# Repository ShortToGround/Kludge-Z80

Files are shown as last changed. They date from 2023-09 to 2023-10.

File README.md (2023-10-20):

# Overview
This is my Z80 homebrew project. I am a total beginner and I'm learning as I go, but the goal is to create a functional kernel and OS based on a Z80 CPU.
The first goal is to get it working for my specific hardware set, the next goal will is to dynamically scan and load drivers as needed, depending on what "cards" are present on boot.

When I say "functional kernel" I mean a real (as real as you can get with a Z80) kernel. Complete with syscalls and memory management.

Programming wisdom says to write your code first and optimize later. I have no doubts that there are many places my code can be optimized.
I don't have a full grasp of every instruction so I will try to get it running first, then go back and make it faster/better later.

**Special thanks to the user Erlend_LB6MI at #electronics on libera IRC and the man behind the Zeal 8-Bit computer project for their guidance.
Check out the Zeal 8-bit computer [here](https://zeal8bit.com). His project is seriously impressive and he even created his own VFS from scratch. His kernel is complete with syscalls and everything. This project is what re-inspired me to finish mine!**

## Current hardware list
I recently switched from LS to HCT ICs for full CMOS Z80 and CF compatiblity.

### CPU/System:
* 1x Z80 CPU - Z84C0010PEG (CMOS)
* 1x Z80/System Clock - ECS-2100AX-100 (10MHz)
* 1x SRAM - CY62256NLL-70PXC (32K)
* 1x EEPROM - AT28C64B-15PU (Unused atm, I'm running everything off of RAM using my rom-uploader program)
* 1x Hex Inverter - SN74AHCT04N
* 1x NAND Gate (Used for some address "decoding")
* 1x OR Gate (Used to combine IOREQ RD/WR into IORD and IOWR. Same for MEMREQ)
* 1x 3-8 Address Decoder - SN74HCT138N
* A crap load of small and medium sized wire
* and a crap load of 104 ceramic capacitors for decoupling (before /u/1Davide on /r/ask_electronics says anything)
UART:
* 1x UART - PC16550DN/NOPB (I have a second one I will probably use for a tape interface one day)
* 1x UART Clock - ECS-100AX-018

### Programming "board"
* 1x Arduino Nano
* 2x Shift Register (Serial In, Parallel Out) - 7SN74HC595N (Wish these were HCT but it seems to work fine)

### Compact Flash:
* CF IDE breakout module

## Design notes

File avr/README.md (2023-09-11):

I think I will end up using some avr MCU's to create the PS/2 controller and maybe even the video circuit

So their source code will be included here when the time comes.

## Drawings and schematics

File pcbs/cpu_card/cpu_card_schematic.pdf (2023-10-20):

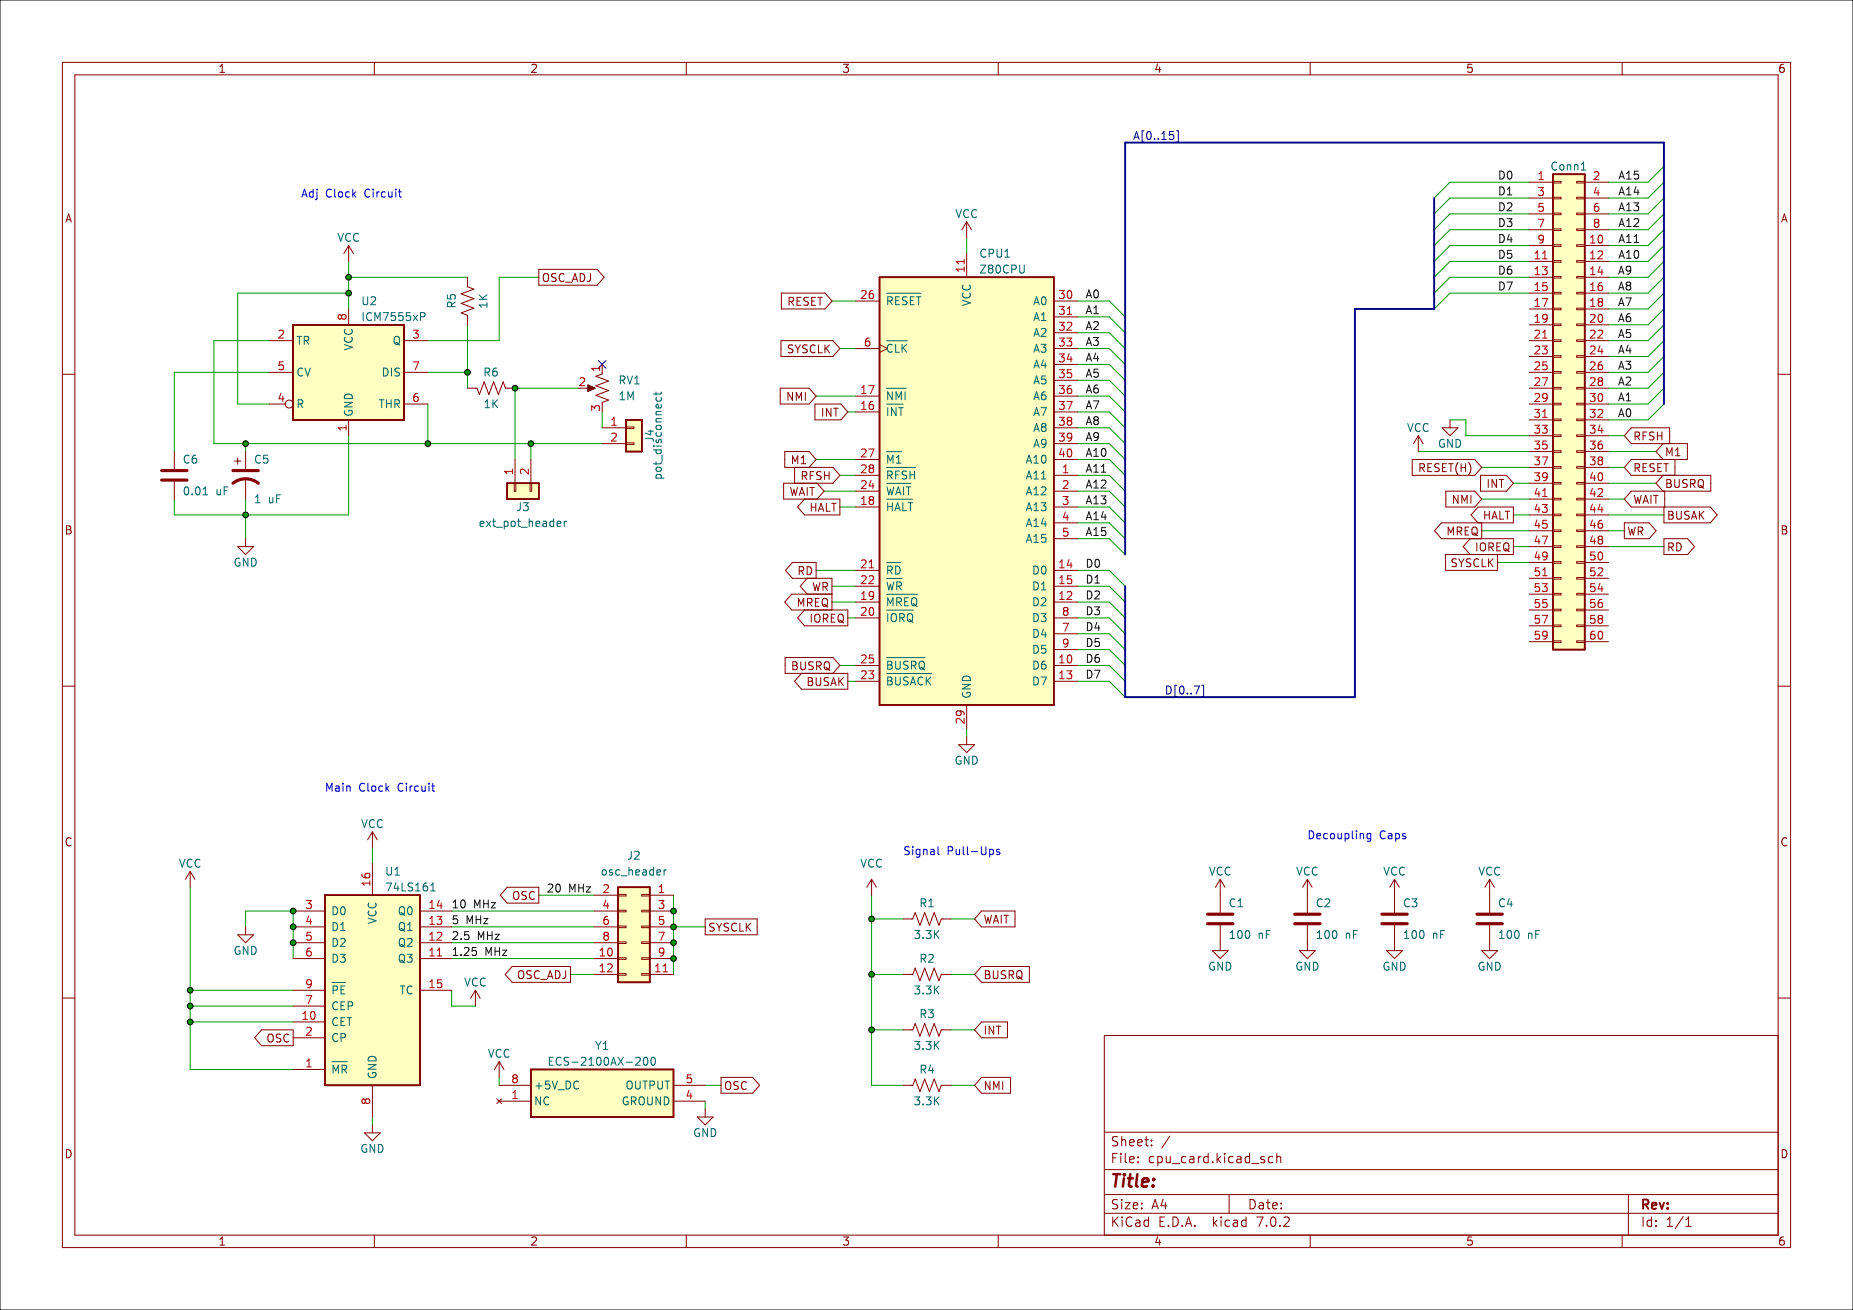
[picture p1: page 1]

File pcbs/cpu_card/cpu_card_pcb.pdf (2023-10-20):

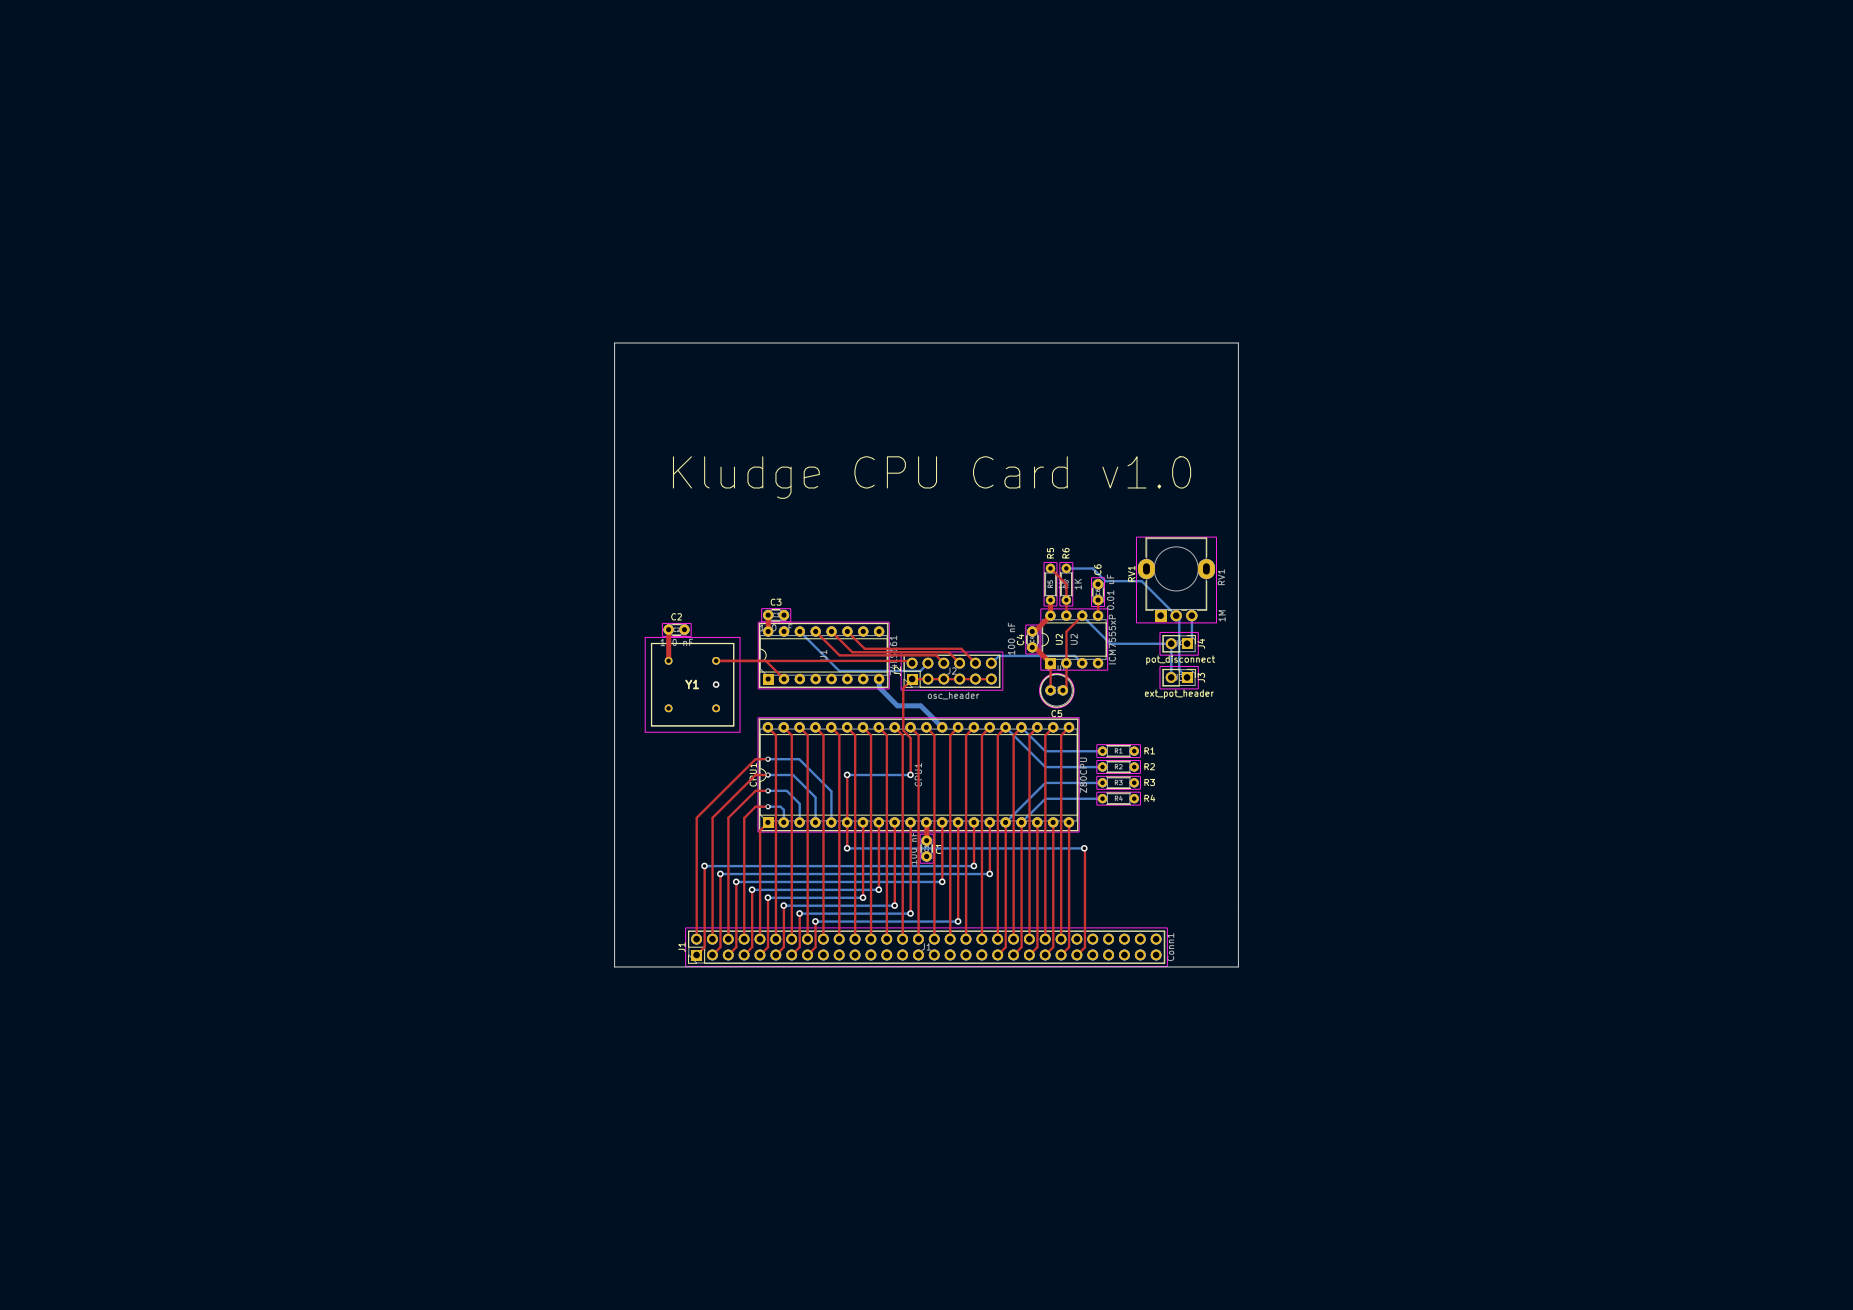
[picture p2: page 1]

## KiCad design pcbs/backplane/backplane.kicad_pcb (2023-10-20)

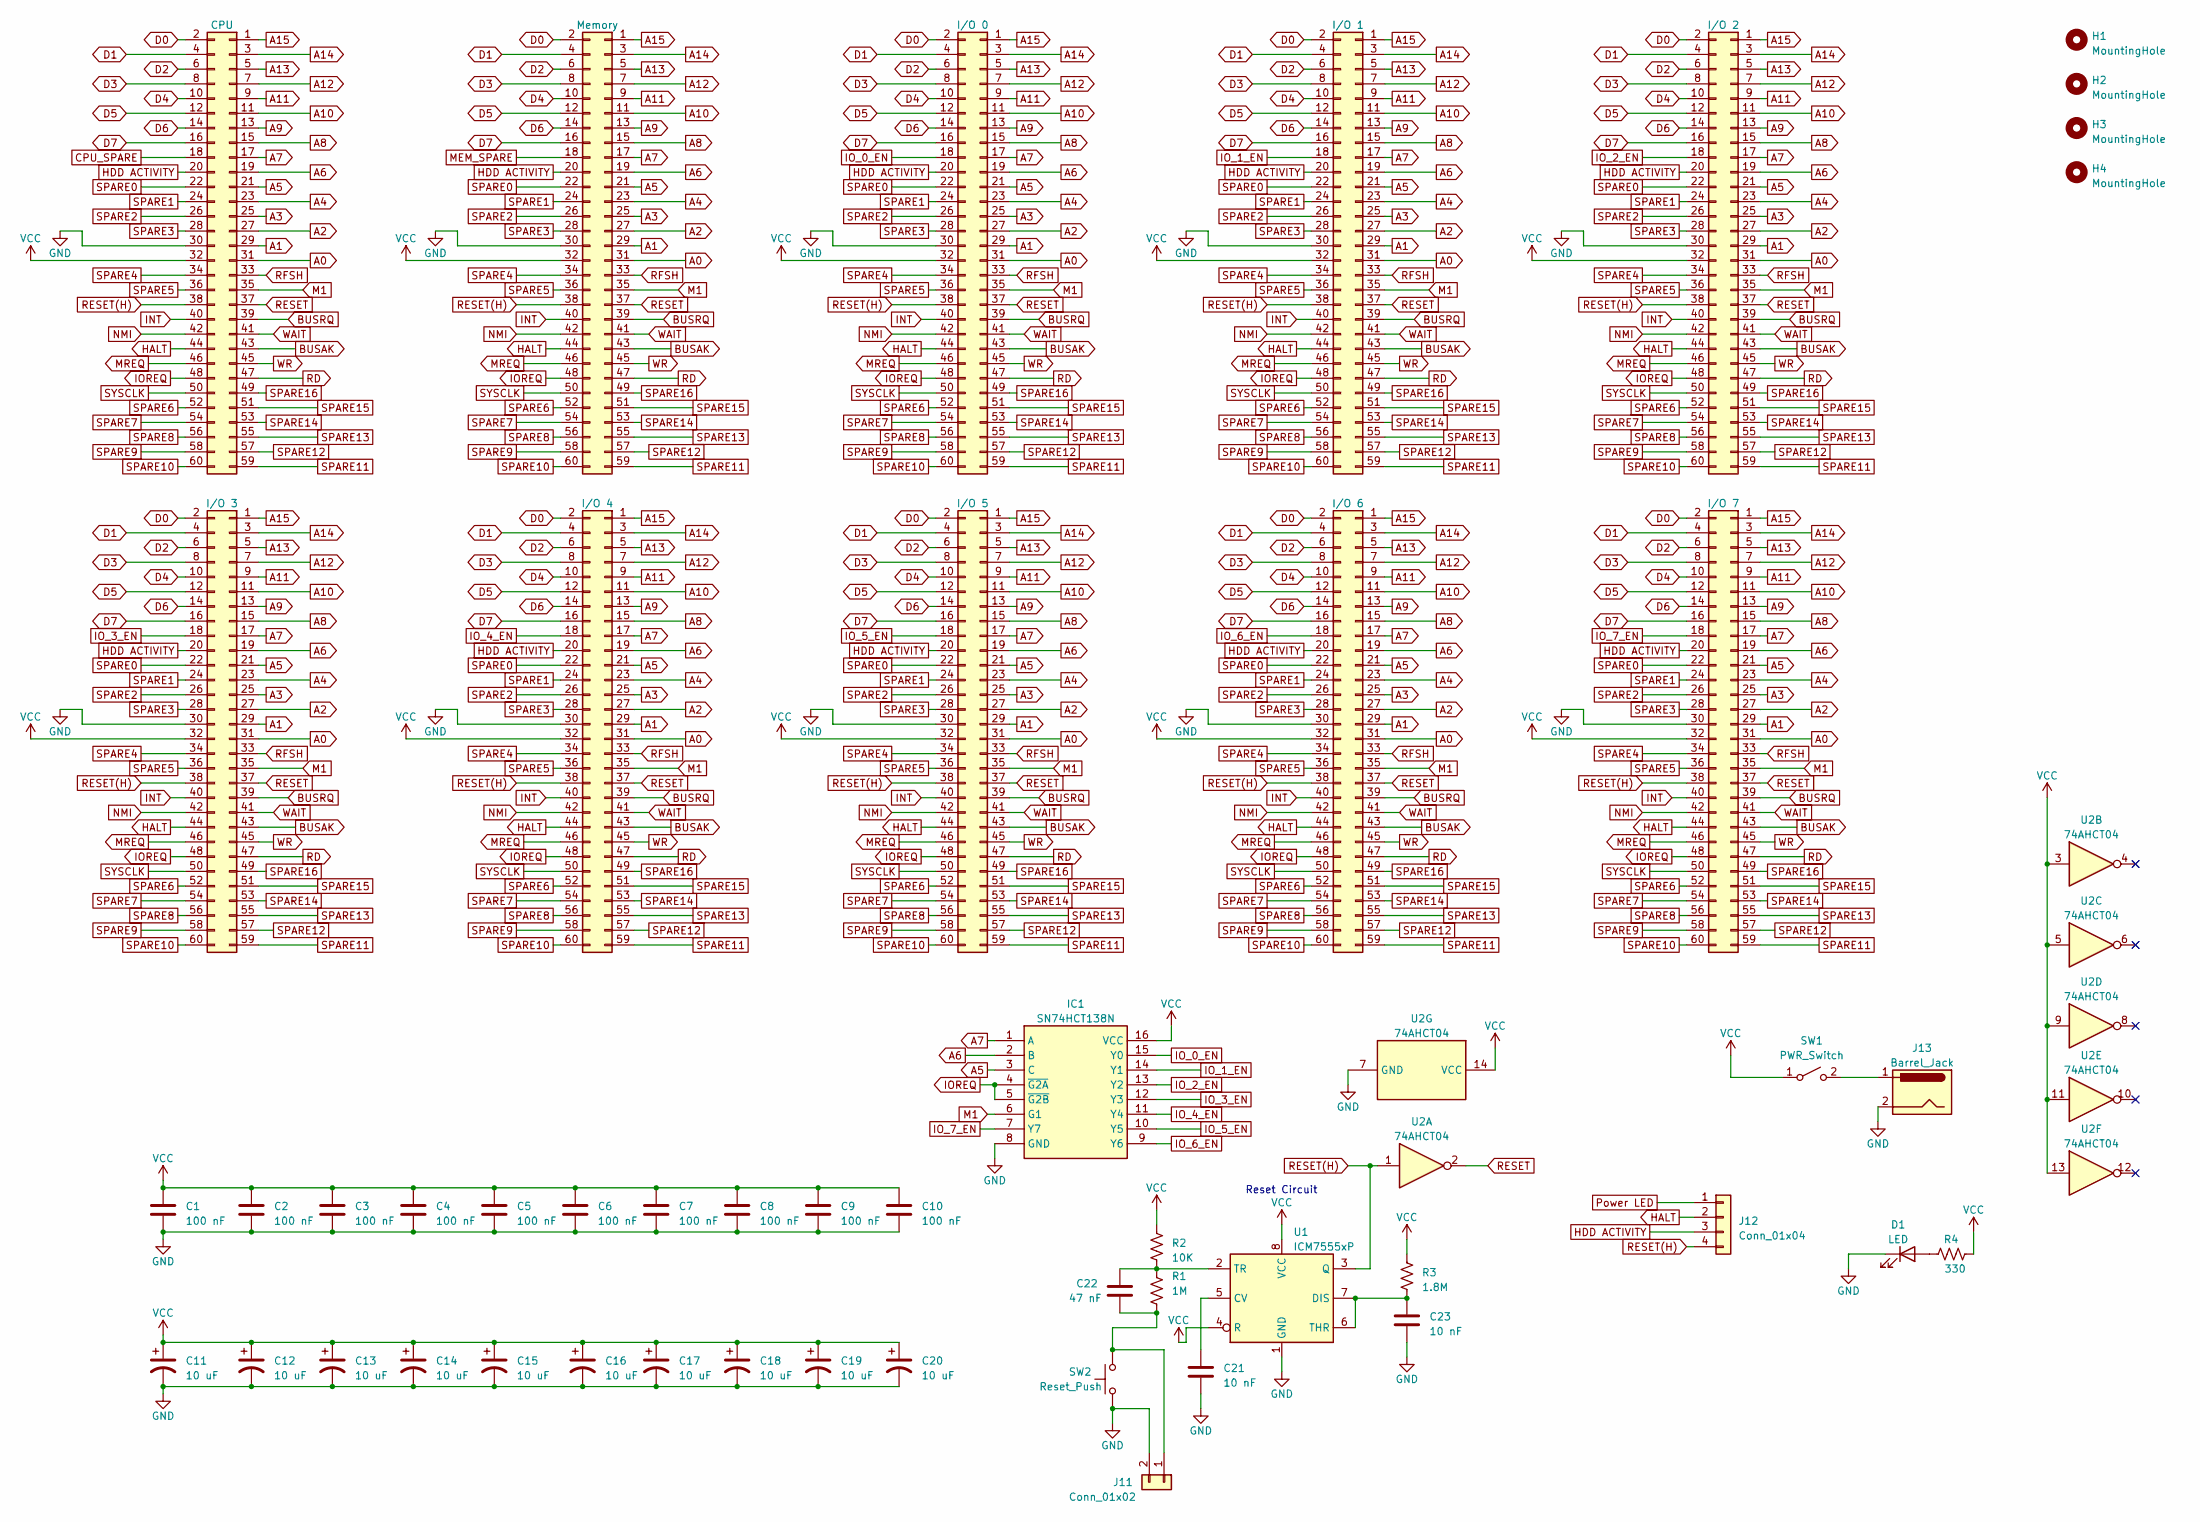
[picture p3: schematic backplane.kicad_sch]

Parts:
C1, C2, C3, C4, C5, C6, C7, C8, C9, C10: 100 nF; C_Disc_D3.0mm_W1.6mm_P2.50mm
C11, C12, C13, C14, C15, C16, C17, C18, C19, C20: 10 uF; C_Radial_D6.3mm_H7.0mm_P2.50mm
C21, C23: 10 nF; C_Disc_D3.0mm_W1.6mm_P2.50mm
C22: 47 nF; C_Disc_D3.0mm_W1.6mm_P2.50mm
D1: LED; LED_D3.0mm
H1, H2, H3, H4: MountingHole; MountingHole_3.2mm_M3
IC1: SN74HCT138N; Mouser Part Number 595-SN74HCT138N
J1: CPU; PinSocket_2x30_P2.54mm_Vertical
J2: Memory; PinSocket_2x30_P2.54mm_Vertical
J3: I/O 0; PinSocket_2x30_P2.54mm_Vertical
J4: I/O 1; PinSocket_2x30_P2.54mm_Vertical
J5: I/O 2; PinSocket_2x30_P2.54mm_Vertical
J6: I/O 3; PinSocket_2x30_P2.54mm_Vertical
J7: I/O 4; PinSocket_2x30_P2.54mm_Vertical
J8: I/O 5; PinSocket_2x30_P2.54mm_Vertical
J9: I/O 6; PinSocket_2x30_P2.54mm_Vertical
J10: I/O 7; PinSocket_2x30_P2.54mm_Vertical
J11: Conn_01x02; PinHeader_1x02_P2.54mm_Vertical
J12: Conn_01x04; PinHeader_1x04_P2.54mm_Vertical
J13: Barrel_Jack; BarrelJack_Horizontal
R1: 1M; R_Axial_DIN0204_L3.6mm_D1.6mm_P5.08mm_Horizontal
R2: 10K; R_Axial_DIN0204_L3.6mm_D1.6mm_P5.08mm_Horizontal
R3: 1.8M; R_Axial_DIN0204_L3.6mm_D1.6mm_P5.08mm_Horizontal
R4: 330; R_Axial_DIN0204_L3.6mm_D1.6mm_P5.08mm_Horizontal
SW1: PWR_Switch; SW_DIP_SPSTx01_Slide_9.78x4.72mm_W7.62mm_P2.54mm
SW2: Reset_Push; SW_PUSH_6mm
U1: ICM7555xP; DIP-8_W7.62mm
U2: 74AHCT04; DIP-14_W7.62mm

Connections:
A0: J1.31, J2.31, J3.31, J4.31, J5.31, J6.31, J7.31, J8.31, J9.31, J10.31
A1: J1.29, J2.29, J3.29, J4.29, J5.29, J6.29, J7.29, J8.29, J9.29, J10.29
A2: J1.27, J2.27, J3.27, J4.27, J5.27, J6.27, J7.27, J8.27, J9.27, J10.27
A3: J1.25, J2.25, J3.25, J4.25, J5.25, J6.25, J7.25, J8.25, J9.25, J10.25
A4: J1.23, J2.23, J3.23, J4.23, J5.23, J6.23, J7.23, J8.23, J9.23, J10.23
A5: IC1.3 (C), J1.21, J2.21, J3.21, J4.21, J5.21, J6.21, J7.21, J8.21, J9.21, J10.21
A6: IC1.2 (B), J1.19, J2.19, J3.19, J4.19, J5.19, J6.19, J7.19, J8.19, J9.19, J10.19
A7: IC1.1 (A), J1.17, J2.17, J3.17, J4.17, J5.17, J6.17, J7.17, J8.17, J9.17, J10.17
A8: J1.15, J2.15, J3.15, J4.15, J5.15, J6.15, J7.15, J8.15, J9.15, J10.15
A9: J1.13, J2.13, J3.13, J4.13, J5.13, J6.13, J7.13, J8.13, J9.13, J10.13
A10: J1.11, J2.11, J3.11, J4.11, J5.11, J6.11, J7.11, J8.11, J9.11, J10.11
A11: J1.9, J2.9, J3.9, J4.9, J5.9, J6.9, J7.9, J8.9, J9.9, J10.9
A12: J1.7, J2.7, J3.7, J4.7, J5.7, J6.7, J7.7, J8.7, J9.7, J10.7
A13: J1.5, J2.5, J3.5, J4.5, J5.5, J6.5, J7.5, J8.5, J9.5, J10.5
A14: J1.3, J2.3, J3.3, J4.3, J5.3, J6.3, J7.3, J8.3, J9.3, J10.3
A15: J1.1, J2.1, J3.1, J4.1, J5.1, J6.1, J7.1, J8.1, J9.1, J10.1
BUSAK: J1.43, J2.43, J3.43, J4.43, J5.43, J6.43, J7.43, J8.43, J9.43, J10.43
BUSRQ: J1.39, J2.39, J3.39, J4.39, J5.39, J6.39, J7.39, J8.39, J9.39, J10.39
CPU_SPARE: J1.18
D0: J1.2, J2.2, J3.2, J4.2, J5.2, J6.2, J7.2, J8.2, J9.2, J10.2
D1: J1.4, J2.4, J3.4, J4.4, J5.4, J6.4, J7.4, J8.4, J9.4, J10.4
D2: J1.6, J2.6, J3.6, J4.6, J5.6, J6.6, J7.6, J8.6, J9.6, J10.6
D3: J1.8, J2.8, J3.8, J4.8, J5.8, J6.8, J7.8, J8.8, J9.8, J10.8
D4: J1.10, J2.10, J3.10, J4.10, J5.10, J6.10, J7.10, J8.10, J9.10, J10.10
D5: J1.12, J2.12, J3.12, J4.12, J5.12, J6.12, J7.12, J8.12, J9.12, J10.12
D6: J1.14, J2.14, J3.14, J4.14, J5.14, J6.14, J7.14, J8.14, J9.14, J10.14
D7: J1.16, J2.16, J3.16, J4.16, J5.16, J6.16, J7.16, J8.16, J9.16, J10.16
GND: C1.2, C2.2, C3.2, C4.2, C5.2, C6.2, C7.2, C8.2, C9.2, C10.2, C11.2, C12.2, C13.2, C14.2, C15.2, C16.2, C17.2, C18.2, C19.2, C20.2, C21.2, C23.2, D1.1 (K), IC1.8 (GND), J1.30, J2.30, J3.30, J4.30, J5.30, J6.30, J7.30, J8.30, J9.30, J10.30, J11.2, J13.2, SW2.1, U1.1 (GND), U2.7 (GND)
HALT: J1.44, J2.44, J3.44, J4.44, J5.44, J6.44, J7.44, J8.44, J9.44, J10.44, J12.2
HDD ACTIVITY: J1.20, J2.20, J3.20, J4.20, J5.20, J6.20, J7.20, J8.20, J9.20, J10.20, J12.3
INT: J1.40, J2.40, J3.40, J4.40, J5.40, J6.40, J7.40, J8.40, J9.40, J10.40
IOREQ: IC1.4 (~G2A), IC1.5 (~G2B), J1.48, J2.48, J3.48, J4.48, J5.48, J6.48, J7.48, J8.48, J9.48, J10.48
IO_0_EN: IC1.15 (Y0), J3.18
IO_1_EN: IC1.14 (Y1), J4.18
IO_2_EN: IC1.13 (Y2), J5.18
IO_3_EN: IC1.12 (Y3), J6.18
IO_4_EN: IC1.11 (Y4), J7.18
IO_5_EN: IC1.10 (Y5), J8.18
IO_6_EN: IC1.9 (Y6), J9.18
IO_7_EN: IC1.7 (Y7), J10.18
M1: IC1.6 (G1), J1.35, J2.35, J3.35, J4.35, J5.35, J6.35, J7.35, J8.35, J9.35, J10.35
MEM_SPARE: J2.18
MREQ: J1.46, J2.46, J3.46, J4.46, J5.46, J6.46, J7.46, J8.46, J9.46, J10.46
NMI: J1.42, J2.42, J3.42, J4.42, J5.42, J6.42, J7.42, J8.42, J9.42, J10.42
unnamed: D1.2 (A), R4.1
unnamed: C22.2, J11.1, R1.2, SW2.2
unnamed: J13.1, SW1.2 (B)
unnamed: C21.1, U1.5 (CV)
unnamed: C23.1, R3.2, U1.6 (THR), U1.7 (DIS)
unnamed: C22.1, R1.1, R2.2, U1.2 (TR)
Power LED: J12.1
RD: J1.47, J2.47, J3.47, J4.47, J5.47, J6.47, J7.47, J8.47, J9.47, J10.47
RESET: J1.37, J2.37, J3.37, J4.37, J5.37, J6.37, J7.37, J8.37, J9.37, J10.37, U2.2
RESET(H): J1.38, J2.38, J3.38, J4.38, J5.38, J6.38, J7.38, J8.38, J9.38, J10.38, J12.4, U1.3 (Q), U2.1
RFSH: J1.33, J2.33, J3.33, J4.33, J5.33, J6.33, J7.33, J8.33, J9.33, J10.33
SPARE0: J1.22, J2.22, J3.22, J4.22, J5.22, J6.22, J7.22, J8.22, J9.22, J10.22
SPARE1: J1.24, J2.24, J3.24, J4.24, J5.24, J6.24, J7.24, J8.24, J9.24, J10.24
SPARE2: J1.26, J2.26, J3.26, J4.26, J5.26, J6.26, J7.26, J8.26, J9.26, J10.26
SPARE3: J1.28, J2.28, J3.28, J4.28, J5.28, J6.28, J7.28, J8.28, J9.28, J10.28
SPARE4: J1.34, J2.34, J3.34, J4.34, J5.34, J6.34, J7.34, J8.34, J9.34, J10.34
SPARE5: J1.36, J2.36, J3.36, J4.36, J5.36, J6.36, J7.36, J8.36, J9.36, J10.36
SPARE6: J1.52, J2.52, J3.52, J4.52, J5.52, J6.52, J7.52, J8.52, J9.52, J10.52
SPARE7: J1.54, J2.54, J3.54, J4.54, J5.54, J6.54, J7.54, J8.54, J9.54, J10.54
SPARE8: J1.56, J2.56, J3.56, J4.56, J5.56, J6.56, J7.56, J8.56, J9.56, J10.56
SPARE9: J1.58, J2.58, J3.58, J4.58, J5.58, J6.58, J7.58, J8.58, J9.58, J10.58
SPARE10: J1.60, J2.60, J3.60, J4.60, J5.60, J6.60, J7.60, J8.60, J9.60, J10.60
SPARE11: J1.59, J2.59, J3.59, J4.59, J5.59, J6.59, J7.59, J8.59, J9.59, J10.59
SPARE12: J1.57, J2.57, J3.57, J4.57, J5.57, J6.57, J7.57, J8.57, J9.57, J10.57
SPARE13: J1.55, J2.55, J3.55, J4.55, J5.55, J6.55, J7.55, J8.55, J9.55, J10.55
SPARE14: J1.53, J2.53, J3.53, J4.53, J5.53, J6.53, J7.53, J8.53, J9.53, J10.53
SPARE15: J1.51, J2.51, J3.51, J4.51, J5.51, J6.51, J7.51, J8.51, J9.51, J10.51
SPARE16: J1.49, J2.49, J3.49, J4.49, J5.49, J6.49, J7.49, J8.49, J9.49, J10.49
SYSCLK: J1.50, J2.50, J3.50, J4.50, J5.50, J6.50, J7.50, J8.50, J9.50, J10.50
VCC: C1.1, C2.1, C3.1, C4.1, C5.1, C6.1, C7.1, C8.1, C9.1, C10.1, C11.1, C12.1, C13.1, C14.1, C15.1, C16.1, C17.1, C18.1, C19.1, C20.1, IC1.16 (VCC), J1.32, J2.32, J3.32, J4.32, J5.32, J6.32, J7.32, J8.32, J9.32, J10.32, R2.1, R3.1, R4.2, SW1.1 (A), U1.4 (R), U1.8 (VCC), U2.3, U2.5, U2.9, U2.11, U2.13, U2.14 (VCC)
WAIT: J1.41, J2.41, J3.41, J4.41, J5.41, J6.41, J7.41, J8.41, J9.41, J10.41
WR: J1.45, J2.45, J3.45, J4.45, J5.45, J6.45, J7.45, J8.45, J9.45, J10.45

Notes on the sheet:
Reset Circuit

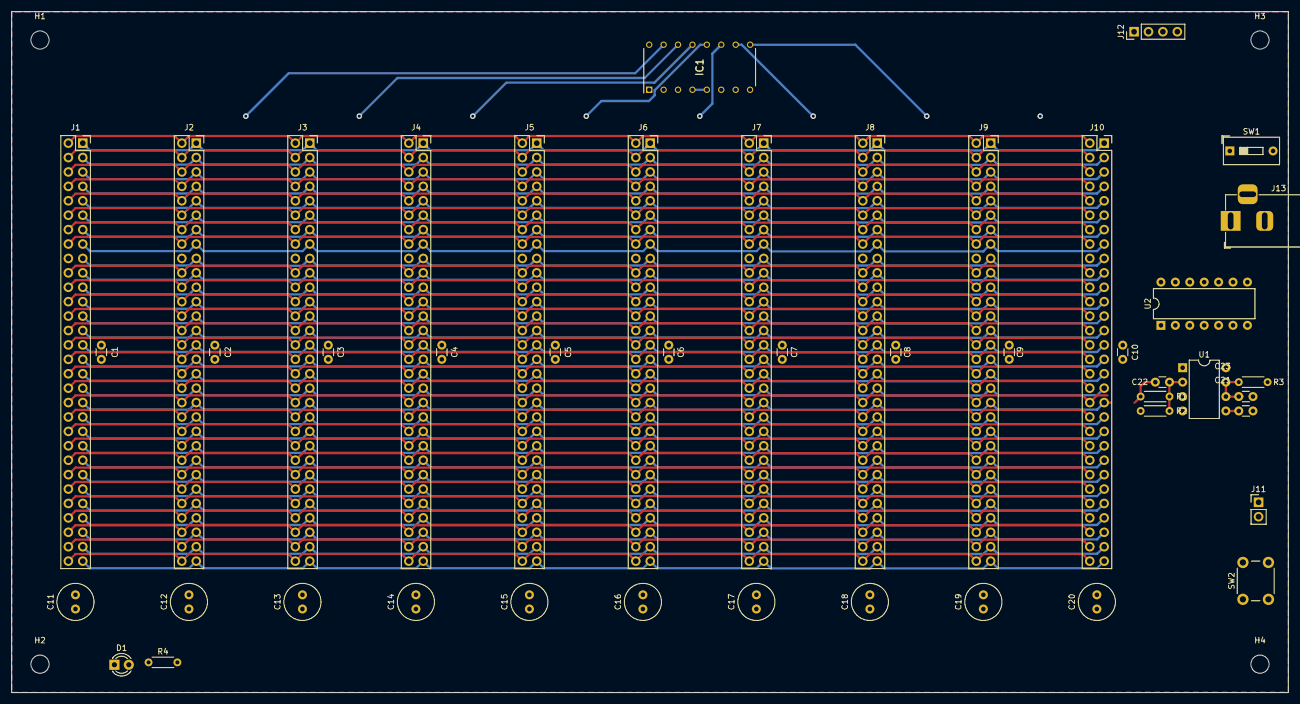
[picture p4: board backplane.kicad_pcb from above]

Board: 4 copper layers, 225.0 x 120.0 mm, 50 parts (0 on the bottom side), 73 nets.

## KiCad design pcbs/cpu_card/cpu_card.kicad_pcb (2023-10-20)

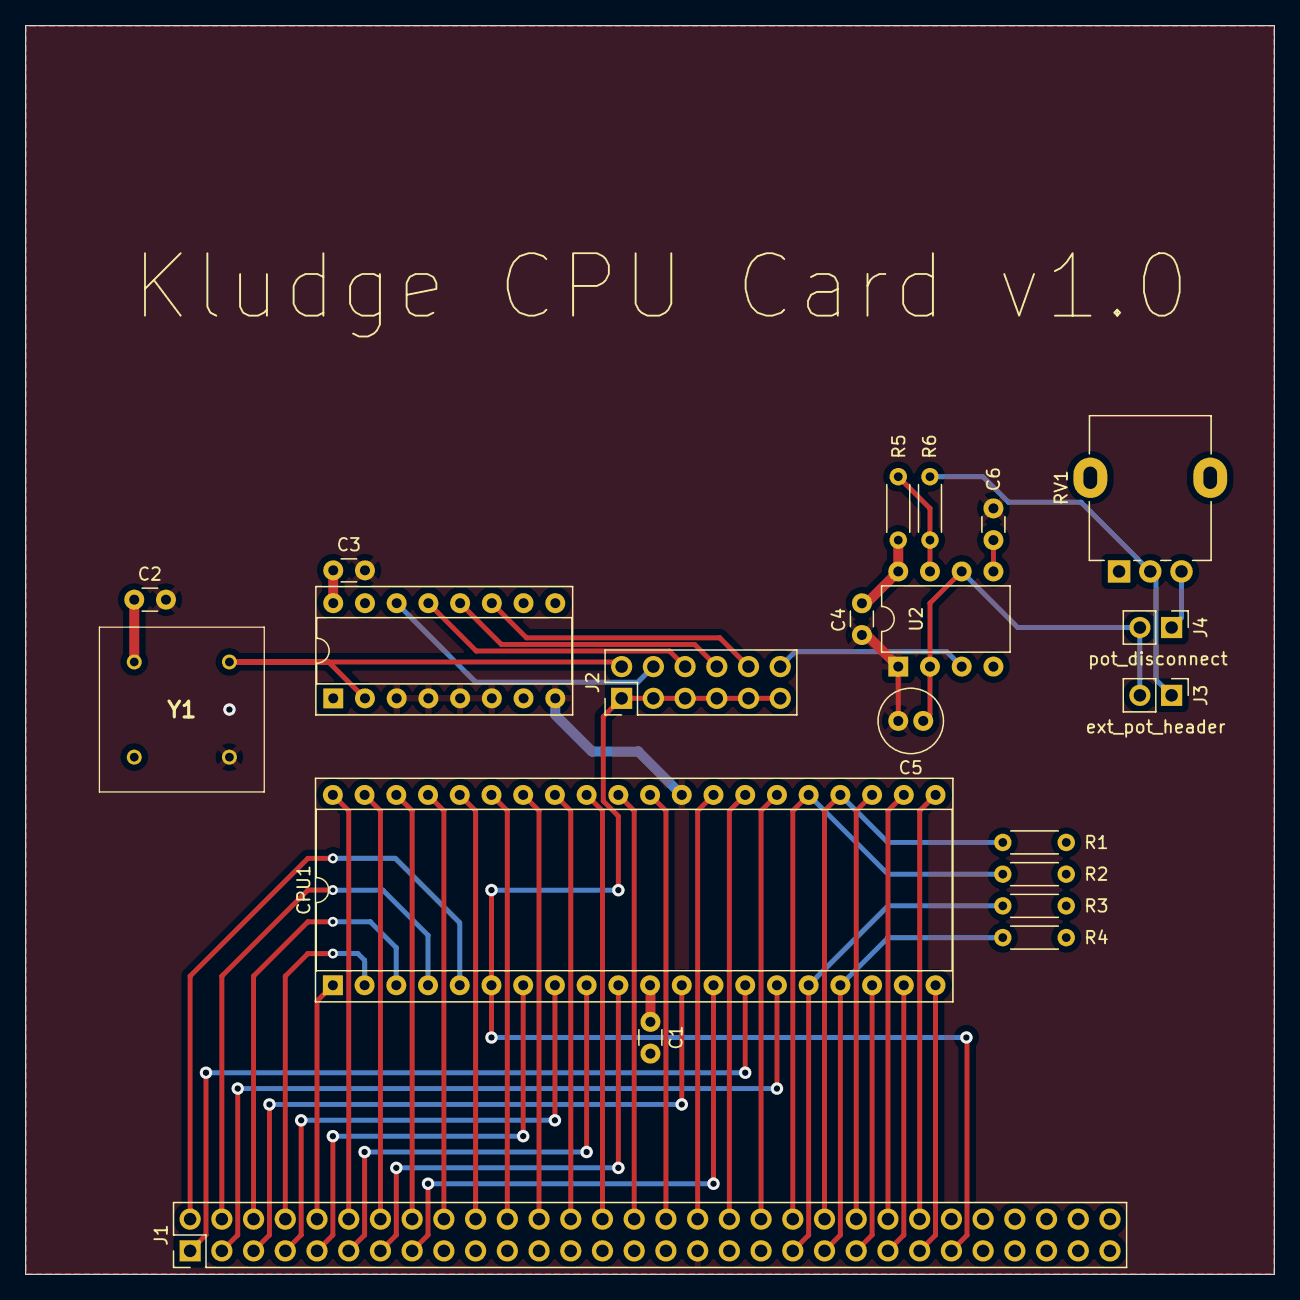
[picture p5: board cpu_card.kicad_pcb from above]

Board: 4 copper layers, 100.0 x 100.0 mm, 21 parts (0 on the bottom side), 51 nets.

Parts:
C1, C2, C3, C4: 100 nF; C_Disc_D3.0mm_W1.6mm_P2.54mm
C5: 1 uF; C_Radial_D5.0mm_H11.0mm_P2.00mm
C6: 0.01 uF; C_Disc_D3.0mm_W1.6mm_P2.54mm
CPU1: Z80CPU; DIP-40_W15.24mm_Socket
J1: Conn1; PinHeader_2x30_P2.54mm_Vertical
J2: osc_header; PinHeader_2x06_P2.54mm_Vertical
J3: ext_pot_header; PinHeader_1x02_P2.54mm_Vertical
J4: pot_disconnect; PinHeader_1x02_P2.54mm_Vertical
R1, R2, R3, R4: 3.3K; R_Axial_DIN0204_L3.6mm_D1.6mm_P5.08mm_Horizontal
R5, R6: 1K; R_Axial_DIN0204_L3.6mm_D1.6mm_P5.08mm_Horizontal
RV1: 1M; Potentiometer_Alpha_RD901F-40-00D_Single_Vertical
U1: 74LS161; DIP-16_W7.62mm_Socket
U2: ICM7555xP; DIP-8_W7.62mm
Y1: ECS-2100AX-200

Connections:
/1.25 MHz: J2.10, U1.11 (Q3)
/2.5 MHz: J2.8, U1.12 (Q2)
/5 MHz: J2.6, U1.13 (Q1)
/10 MHz: J2.4, U1.14 (Q0)
/A0: CPU1.30 (A0), J1.32
/A1: CPU1.31 (A1), J1.30
/A2: CPU1.32 (A2), J1.28
/A3: CPU1.33 (A3), J1.26
/A4: CPU1.34 (A4), J1.24
/A5: CPU1.35 (A5), J1.22
/A6: CPU1.36 (A6), J1.20
/A7: CPU1.37 (A7), J1.18
/A8: CPU1.38 (A8), J1.16
/A9: CPU1.39 (A9), J1.14
/A10: CPU1.40 (A10), J1.12
/A11: CPU1.1 (A11), J1.10
/A12: CPU1.2 (A12), J1.8
/A13: CPU1.3 (A13), J1.6
/A14: CPU1.4 (A14), J1.4
/A15: CPU1.5 (A15), J1.2
/D0: CPU1.14 (D0), J1.1
/D1: CPU1.15 (D1), J1.3
/D2: CPU1.12 (D2), J1.5
/D3: CPU1.8 (D3), J1.7
/D4: CPU1.7 (D4), J1.9
/D5: CPU1.9 (D5), J1.11
/D6: CPU1.10 (D6), J1.13
/D7: CPU1.13 (D7), J1.15
BUSAK: CPU1.23 (~BUSACK), J1.44
BUSRQ: CPU1.25 (~BUSRQ), J1.40, R2.1
GND: C1.2, C2.2, C3.2, C4.2, C5.2, C6.2, CPU1.29 (GND), J1.33, U1.3 (D0), U1.4 (D1), U1.5 (D2), U1.6 (D3), U1.8 (GND), U2.1 (GND), Y1.4 (GROUND)
HALT: CPU1.18 (~HALT), J1.43
INT: CPU1.16 (~INT), J1.39, R3.1
IOREQ: CPU1.20 (~IORQ), J1.47
M1: CPU1.27 (~M1), J1.36
MREQ: CPU1.19 (~MREQ), J1.45
NMI: CPU1.17 (~NMI), J1.41, R4.1
unnamed: J3.1, R6.2, RV1.2
unnamed: C5.1, J3.2, J4.2, U2.2 (TR), U2.6 (THR)
unnamed: J4.1, RV1.3
unnamed: C6.1, U2.5 (CV)
unnamed: R5.2, R6.1, U2.7 (DIS)
OSC: J2.2, U1.2 (CP), Y1.5 (OUTPUT)
OSC_ADJ: J2.12, U2.3 (Q)
RD: CPU1.21 (~RD), J1.48
RESET: CPU1.26 (~RESET), J1.38
RFSH: CPU1.28 (~RFSH), J1.34
SYSCLK: CPU1.6 (~CLK), J1.49, J2.1, J2.3, J2.5, J2.7, J2.9, J2.11
VCC: C1.1, C2.1, C3.1, C4.1, CPU1.11 (VCC), J1.35, R1.2, R2.2, R3.2, R4.2, R5.1, U1.1 (~MR), U1.7 (CEP), U1.9 (~PE), U1.10 (CET), U1.15 (TC), U1.16 (VCC), U2.4 (R), U2.8 (VCC), Y1.8 (+5V_DC)
WAIT: CPU1.24 (~WAIT), J1.42, R1.1
WR: CPU1.22 (~WR), J1.46

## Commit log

2023-09-11 added color pcb pdf file
2023-09-11 changed signal traces from 0.25mm to 0.3mm and moved a few traces arround to accommodate the new size
    [cpu_card.kicad_pcb]
2023-09-11 Added active-high reset to bus
    [cpu_card.kicad_sch]
2023-09-12 Changed Z80 input pull-up resistors to lower values to account for transition time at 10Mhz
    [cpu_card.kicad_sch]
2023-09-13 exported pcb so it is easier to see
2023-09-21 Changed the bus hardware to 2.54mm header and cleaned up the CPU card PCB layout
    [cpu_card.kicad_pcb, cpu_card.kicad_sch]
2023-09-21 Changed CPU board to nominal 20MHz with the option to adjust using the 2x5 header.
    [cpu_card.kicad_pcb, cpu_card.kicad_sch]
2023-10-20 Mostly finished with cpu_card, added early prototypes of backplane and protoboard cards. Also added the libraries used for this project
    [backplane.kicad_pcb, backplane.kicad_sch, cpu_card.kicad_pcb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]
